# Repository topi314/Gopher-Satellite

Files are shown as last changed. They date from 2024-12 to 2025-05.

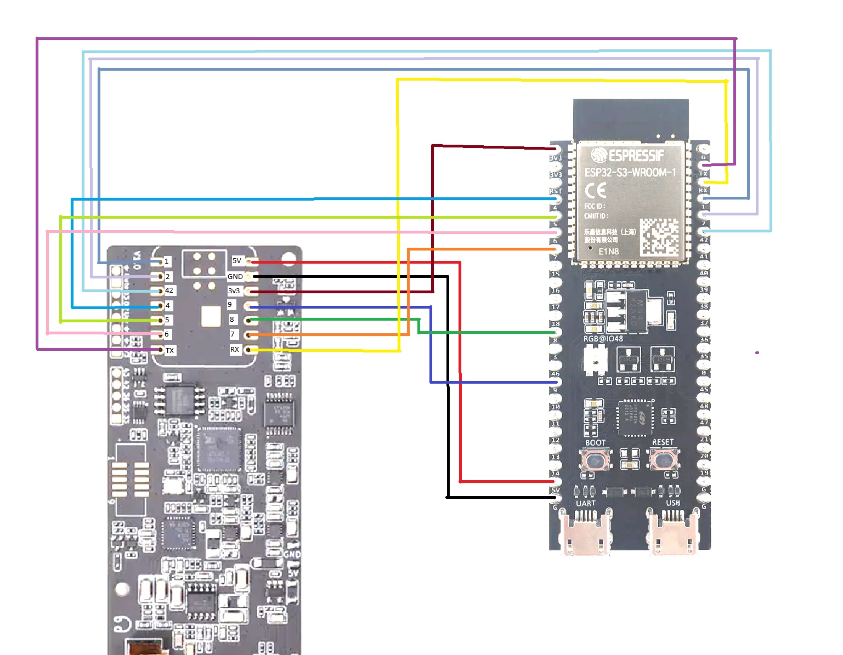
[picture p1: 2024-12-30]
instructions/images/respeaker-esp-pinout.jpg

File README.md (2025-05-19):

# Gopher Satellite

Gopher Satellite is a DIY device that works as a satellite for Home Assistant Assist.

## It is based on [Koala-Satellite](https://github.com/formatBCE/Koala-Satellite) from [formatBCE](https://github.com/formatBCE) check it out and buy him a coffee :coffee:!

#### Main characteristics:

- two far-field microphones, coupled with XMOS chip XU-316 for noise cancelation and voice recognition;
- 16bit 48kHz audio output;
- 5W speaker to use for speech responses, announcements, chimes or music;
- hardware mute button;
- rotary encoder for volume change and other adjustments;
- RGB LED for status displaying or mood lighting;
- 3.5mm line-out jack to connect external speaker.

#### Appreciation

I'd like to thank to formatBCEmm NabuCasa team and Home Assistant project - this project firmware is almost completely based on their work, and created for Home Assistant exclusively.
My dedicated appreciation goes to the [Voice PE](https://github.com/esphome/home-assistant-voice-pe) team, that made all of this possible.
Also, i'm thankful for continuous support from Seeed developers. We spent days debugging Respeaker Lite software. Now it works great!

#### How is it different from [Koala-Satellite](https://github.com/formatBCE/Koala-Satellite)?\

TLDR: I got some slightly different hardware.

//TODO: state different hardware

#### How is it different from Home Assistant [Voice PE](https://www.home-assistant.io/voice-pe)?

They're actually pretty similar. I used PE ESPHome software as the base for Koala software, and many parts are working identically.
They connect to Home Assistant in the same way and have identical possibilities.
Koala is just something you can assemble yourself from widely accessible parts.
Also it has pretty decent for size audio speaker and doesn't have external sensors connectors.

#### How is it different from [this repository](https://github.com/formatBCE/Respeaker-Lite-ESPHome-integration)?

I started to work with [Respeaker Lite](https://www.seeedstudio.com/ReSpeaker-Lite-p-5928.html) several months ago.
That repository was my attempt to put everything i know together.
All the process is pretty much documented in [this Home Assistant Community thread](https://community.home-assistant.io/t/respeaker-lite-new-seeed-studio-voice-assistant-development-kit-hardware-combine-esp32-with-xmos-xu316-dsp-chip-for-advanced-au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).
At some point i made Echo-Pop-like enclosure to the Respeaker Lite Kit. But it had disadvantages, like gluing face plate (or fabric), no access to ESP and Respeaker USB ports, lack of volume controls and rudimentary LED.
So i started thinking on real device. Here it is.

#### Why not use [Respeaker Lite with pre-soldered XIAO ESP32-S3 board](https://www.seeedstudio.com/ReSpeaker-Lite-Voice-Assistant-Kit-p-5929.html)? Isn't that easier and cheaper?

Yes, it is. But pretty much all exposed ESP GPIO pins are used by Respeaker in that configuration. So there's no way to use more elements like rotary or LED strip.
Also, current configuration hides nicely USB power cable (which is also ESP32 data cable), and allows exposing RESET/BOOT buttons for flashing.
If you're using pre-soldered version, you may check [this PR by @rananna](https://github.com/formatBCE/Koala-Satellite/pull/5) _(Thank you!)_.
Or even go full bananas and use it without dedicated LED strip (top LED should work okay) - just adjust LED diffuser color to your like.

### [Here's how you make one for yourself.](/instructions/assembly.md)

### Check main abilities [here on Respeaker repository](https://github.com/formatBCE/Respeaker-Lite-ESPHome-integration/tree/main?tab=readme-ov-file#current-abilities) - they're identical

### What if i don't want or cannot build it myself?

Create issue in this repository to let me know, that you need fully assembled device (or just printed enclosure for it). I will consider selling if demand is there. :)

"Buy Me A Coffee" (https://www.buymeacoffee.com/formatbce)

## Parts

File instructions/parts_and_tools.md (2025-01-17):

### Parts used

- microphones and DAC/AMP: Respeaker Lite board (bare board, without XIAO-S3 soldered on, like [this](https://www.seeedstudio.com/ReSpeaker-Lite-p-5928.html));
- main board: ESP32-S3 DevkitC N16R8 like [this](https://www.amazon.de/dp/B0DHJXTYBJ) (they seem to have issues with wifi & TX pin);
- rotary encoder: KY-040 ([i used this](https://a.co/d/8K1tguS));
- LED: 144 diodes/meter addressable WS2812B, 43 diodes long ([i used this](https://a.co/d/c7r4G9y));
- speaker: 2" 4Ohm 5W ([example](https://a.co/d/cEpEeNt));
- 10x M3 screws ([i used this set](https://a.co/d/e6pNfBu));
- 10x threaded inserts ([i used this](https://a.co/d/bMeMx9B));
- Jst 2.0 Ph 2-Pin Connector (male and female) for speaker like [this](https://a.co/d/aUkOTCS);
- some 3-wired male-female connector for easy LED strip connection ([i used one from this kit](https://a.co/d/9OdHJpC));
- cords of various length;
- 4x sticky rubber pads (to isolate enclosure vibrations from surface it's standing on).

### Tools used

- soldering iron and accessories;
- screwdriver or allen wrench for screws.

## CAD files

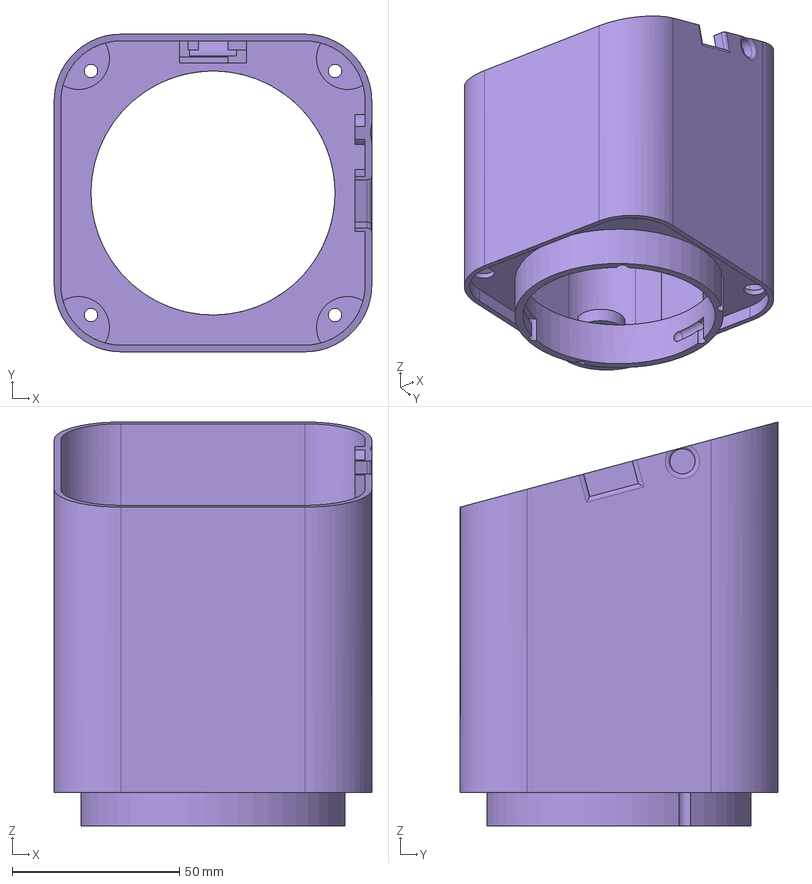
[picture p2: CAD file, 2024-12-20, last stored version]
casing/step/Main casing.step
95.0 x 95.0 x 120.8 mm

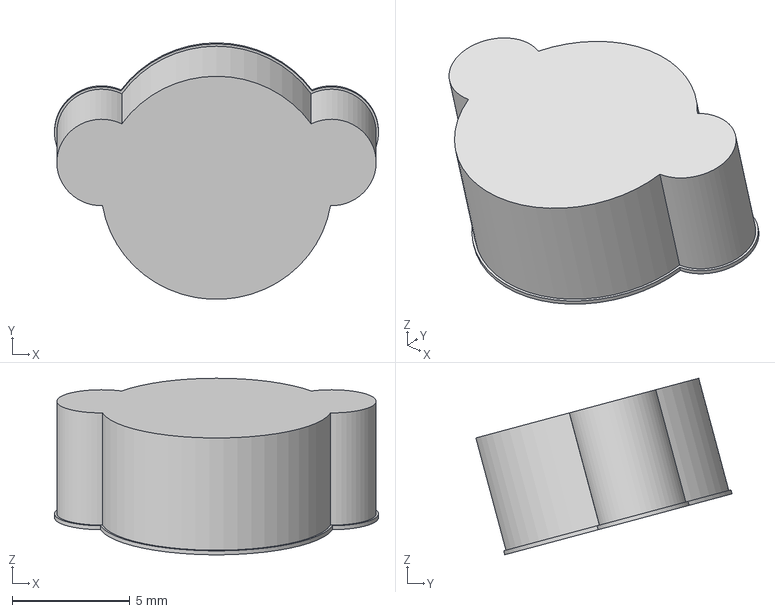
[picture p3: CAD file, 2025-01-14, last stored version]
casing/step/Top LED cover.step
13.7 x 10.9 x 7.49 mm

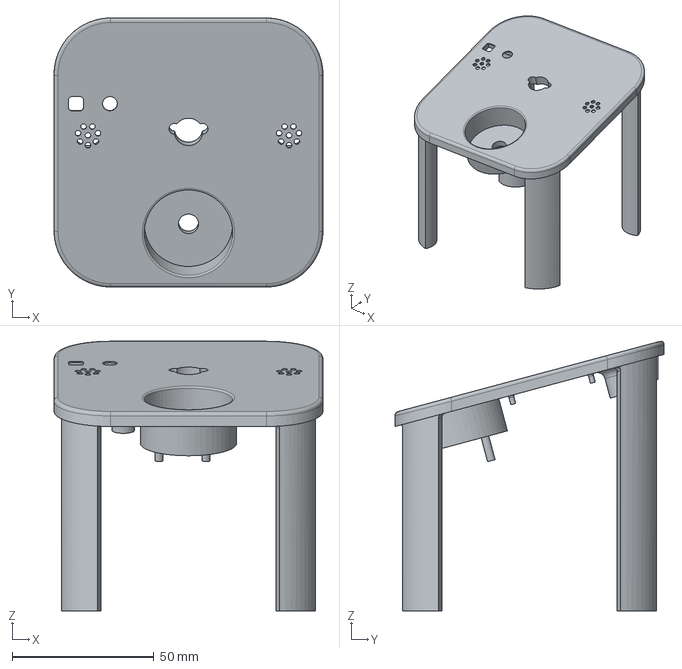
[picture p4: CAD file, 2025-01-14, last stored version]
casing/step/Face plate for top LED cover.step
95.0 x 95.0 x 95.2 mm

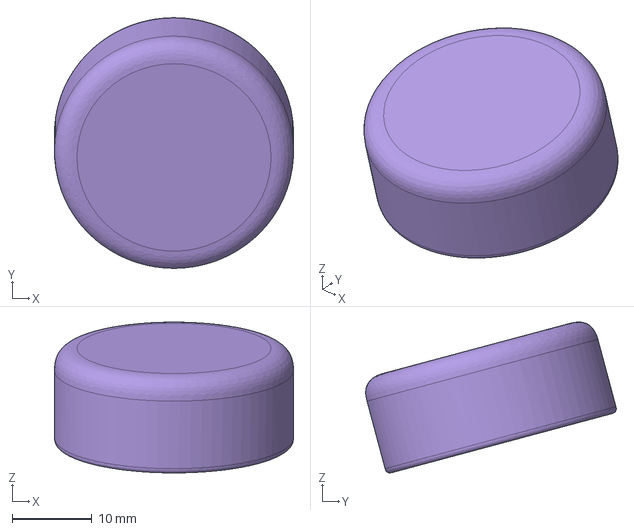
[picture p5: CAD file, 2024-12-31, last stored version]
casing/step/Knob.step
30.0 x 31.4 x 18.9 mm

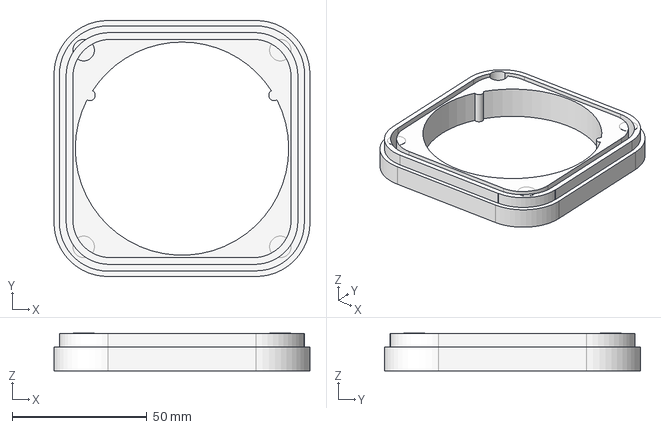
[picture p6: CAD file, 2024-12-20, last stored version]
casing/step/LED diffuser.step
95.0 x 95.0 x 14.0 mm

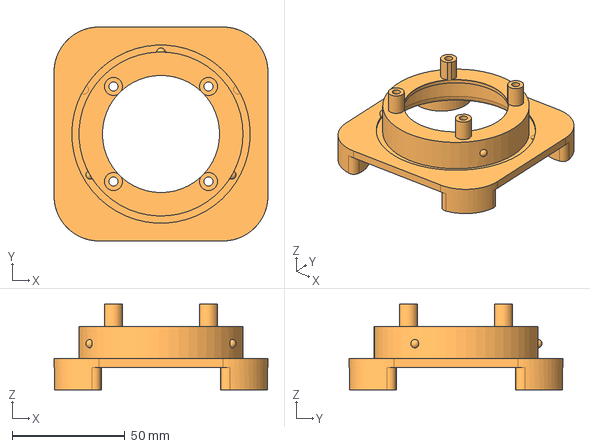
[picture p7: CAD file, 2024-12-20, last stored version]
casing/step/Speaker plate.step
95.0 x 95.0 x 38.0 mm

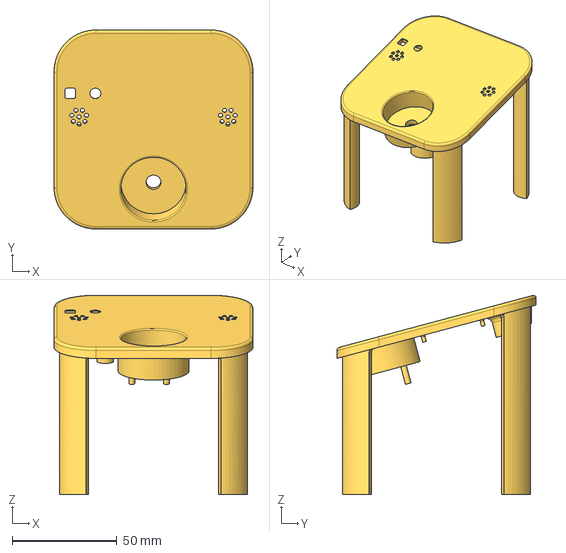
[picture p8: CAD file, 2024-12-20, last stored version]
casing/step/Face plate.step
95.0 x 95.0 x 95.2 mm

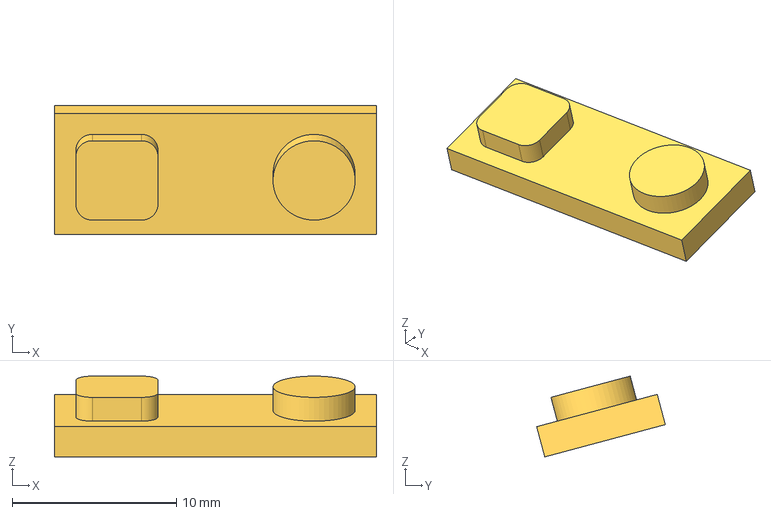
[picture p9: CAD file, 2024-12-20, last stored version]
casing/step/Buttons.step
19.6 x 7.83 x 4.92 mm

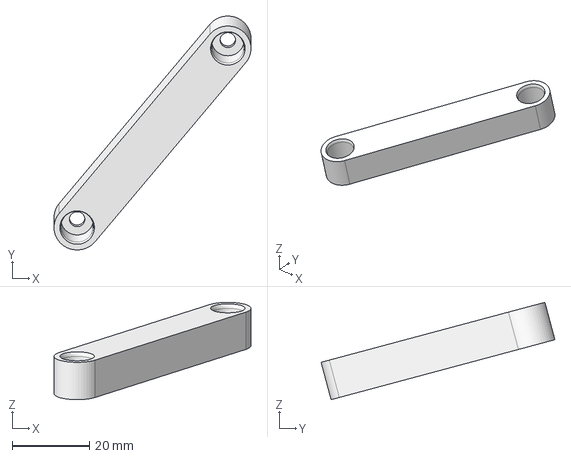
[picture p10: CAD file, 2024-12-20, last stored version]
casing/step/Bracket.step
51.0 x 60.5 x 25.2 mm

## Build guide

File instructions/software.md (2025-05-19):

## Installing the Gopher firmware

### Flashing DFU software to Respeaker Lite

To flash Respeaker board with correct software, you can use [included sowtware](/respeaker_lite_i2s_dfu_firmware_48k_v1.1.0.bin) (or take one with version >= 1.1.0 and 48kHz sample rate from [official repo](https://github.com/respeaker/ReSpeaker_Lite/tree/master/xmos_firmwares)) with [instructions from Seeed site](https://wiki.seeedstudio.com/xiao_respeaker/#flash-the-i2s-firmware).

#### _Please re-insert the board after flash and make sure that displayed version is correct one._

### DFU software auto-update
Since version 2025.2.2, the Koala firmware includes corresponding DFU firmware for Respeaker Lite board. On first start after update, new firmware will be installed to Respeaker automatically. You will see Respeaker LED flashing yellow, while installing, and green on successful install.
So now there's no need to update DFU firmware. Woohoo!

### Flashing ESPHome configuration to ESP32-S3 board

There's a configuration available: [dashboard](/config/gopher-dashboard.yaml). Also you will need to copy [base config YAML](/config/common/gopher-base.yaml) into `common` directory in your ESPHome root folder. Alternatively, you can copy everything from `gopher-base.yaml` to the chosen config and merge everything inside.

Build the firmware with ESPHome and flash it with your method of choice.

### Connecting to Home Assistant

- I'm sure you already know how to connect ESPHome devices to Home Assistant. If it's your first time, please check the [official documentation](https://www.home-assistant.io/integrations/esphome/).
- In case of Factory firmware you will need to connect the device to the WiFi first. Check [Improv docs](https://www.home-assistant.io/integrations/improv_ble/) for details.
  _**(When asked to authorize by pressing button on device, use small round button!)**_
- The voice satellite onboarding wizard will help you setup the pipeline and wake word.

### Using the alarm functionality.
Since 2025.4.1, the device has built-in alarm, that you can setup and use in your smart home. Check [this short tutorial](https://github.com/formatBCE/Respeaker-Lite-ESPHome-integration/blob/ae414e06fea8334e726837d5dbe72a55645b3445/readme/alarms.md) on how to set it up!

### _Happy tinkering!_

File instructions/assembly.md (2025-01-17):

## Gopher assembly process.

### First, check out and order required [parts and tools](parts_and_tools.md).

You don't have to use exactly the parts i used - but make sure that your parts will fit to the casing.
For example, threaded inserts holes are 4mm, count on that.
The rotary encoder is pretty specific, but it's widely accessible.
Same goes to ESP32-S3 board. Make sure it has sticking antenna - the casing made for it. You'll find over9000 clones on Amazon, and mostly (!) they will be decent. Just make sure the board works before proceeding.

### Prepare guts

- Bridge buttons on Respeaker Lite to corresponding pins (`USR` to `D2`, `Mute` to `D3`).
- Bridge `IN-OUT` and `RGB` with solder on ESP board.
- Solder the male Jst 2.0 Ph 2-Pin Connector to the speaker. Keep the cable short, ~3cm.
- Solder the female Jst 2.0 Ph 2-Pin Connector to the Respeaker Lite. You will find corresponding pads on Respeaker board near the soldered JST connector (marked + and -). Check the cables polarity. Make the cable long, so it sticks from the bottom of main casing, when Respeaker is on top (~12cm).
- Cut 43 LED long piece of WS2812 strip. Make sure it will fit LED diffuser slot nicely. Start from round hole, and move clockwise when placing the strip into diffuser.
- Solder cables of 3-wire connector male part to the LED strip. Keep these cables ~5cm long. Check the wiring. I prefer to color-code (5v -> red, GND -> black, data -> other colour).
- Solder cables of 3-wire LED connector female part to the ESP board. Make these cables ~7cm long.
  - power -> `5V`
  - ground -> `GND`
  - data -> `GPIO13`
- Solder the rotary encoder to ESP board. Make sure cables length is enough for mounting, but not too long.
  - `+` -> `5V`
  - `GND` -> `GND`
  - `SW` -> `GPIO20`
  - `CLK` -> `GPIO47`
  - `DT` -> `GPIO21`
- Solder all Respeaker Lite pins to the ESP board. This will take some time.
  - Check pinout on [this image](images/respeaker-esp-pinout.jpg).

#### At this stage, you can [install the firmware](software.md), connect the peripherals and check that everything works.

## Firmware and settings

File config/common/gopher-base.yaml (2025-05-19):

substitutions:
  # Phases of the Voice Assistant
  # The voice assistant is ready to be triggered by a wake word
  voice_assist_idle_phase_id: "1"
  # The voice assistant is waiting for a voice command (after being triggered by the wake word)
  voice_assist_waiting_for_command_phase_id: "2"
  # The voice assistant is listening for a voice command
  voice_assist_listening_for_command_phase_id: "3"
  # The voice assistant is currently processing the command
  voice_assist_thinking_phase_id: "4"
  # The voice assistant is replying to the command
  voice_assist_replying_phase_id: "5"
  # The voice assistant is not ready
  voice_assist_not_ready_phase_id: "10"
  # The voice assistant encountered an error
  voice_assist_error_phase_id: "11"

esphome:
  project:
    name: topi314.Gopher Satellite
    version: 2025.4.0
  name: gopher-satellite
  friendly_name: Gopher Satellite
  name_add_mac_suffix: true
  min_version: 2025.3.3
  platformio_options:
    board_build.flash_mode: dio
  on_boot:
    - priority: 375
      then:
        # Reset next timer and next timer name
        - sensor.template.publish:
            id: next_timer
            state: -1
        - text_sensor.template.publish:
            id: next_timer_name
            state: "-1"
        # Run the script to refresh the LED status
        - script.execute: control_leds
        # If after 10 minutes, the device is still initializing (It did not yet connect to Home Assistant), turn off the init_in_progress variable and run the script to refresh the LED status
        - delay: 10min
        - if:
            condition:
              lambda: return id(init_in_progress);
            then:
              - lambda: id(init_in_progress) = false;
              - script.execute: control_leds
  on_shutdown:
    then:
      # Prevent loud noise on software restart
      - lambda: id(respeaker).mute_speaker();

esp32:
  board: esp32-s3-devkitc-1
  variant: esp32s3
  flash_size: 16MB
  framework:
    type: esp-idf
    version: recommended
    sdkconfig_options:
      CONFIG_ESP32S3_DEFAULT_CPU_FREQ_240: "y"
      CONFIG_ESP32S3_DATA_CACHE_64KB: "y"
      CONFIG_ESP32S3_DATA_CACHE_LINE_64B: "y"
      CONFIG_ESP32S3_INSTRUCTION_CACHE_32KB: "y"

      CONFIG_BT_ALLOCATION_FROM_SPIRAM_FIRST: "y"
      CONFIG_BT_BLE_DYNAMIC_ENV_MEMORY: "y"

      CONFIG_MBEDTLS_EXTERNAL_MEM_ALLOC: "y"
      CONFIG_MBEDTLS_SSL_PROTO_TLS1_3: "y" # TLS1.3 support isn't enabled by default in IDF 5.1.5

wifi:
  id: wifi_id
  power_save_mode: none
  fast_connect: ${fast_connect}
  output_power: 19dB # seems like wifi on my board sucks lol
  on_connect:
    - script.execute: control_leds
  on_disconnect:
    - script.execute: control_leds

logger:
  level: debug
  initial_level: debug
  logs:
    sensor: WARN # avoids logging debug sensor updates
  # hardware_uart: uart0 #Uncomment to see serial logs via USB connection. Comment out after debufgging - this line introduces noise on speaker...

select:
  - platform: logger
    id: logger_select
    name: Logger Level
    disabled_by_default: true

debug:
  update_interval: 5s

api:
  id: api_id
  actions:
    - action: start_va
      then:
        - voice_assistant.start
    - action: stop_va
      then:
        - voice_assistant.stop
  on_client_connected:
    - script.execute: control_leds
  on_client_disconnected:
    - script.execute: control_leds

# Uncomment this, if you have problems with text-to-speech because of Home Assistant HTTPS internal URL
# http_request:
#   verify_ssl: false

ota:
  - platform: esphome
    id: ota_esphome

i2c:
  - id: internal_i2c
    sda: GPIO5
    scl: GPIO6
    frequency: 400kHz
  - id: display_i2c
    sda: GPIO11
    scl: GPIO10
    frequency: 400kHz

psram:
  mode: octal
  speed: 80MHz

globals:
  # Global initialization variable. Initialized to true and set to false once everything is connected. Only used to have a smooth "plugging" experience
  - id: init_in_progress
    type: bool
    restore_value: false
    initial_value: "true"
  # Global variable tracking the phase of the voice assistant (defined above). Initialized to not_ready
  - id: voice_assistant_phase
    type: int
    restore_value: false
    initial_value: ${voice_assist_not_ready_phase_id}
  # Global variable storing the time zone
  - id: saved_time_zone
    type: std::string
    restore_value: true
    initial_value: '"UTC0"'
  # Global variable storing the first active timer
  - id: first_active_timer
    type: voice_assistant::Timer
    restore_value: false
  # Global variable storing if a timer is active
  - id: is_timer_active
    type: bool
    restore_value: false
  # Global variable storing the current ringing timer
  - id: current_ringing_timer
    type: voice_assistant::Timer
    restore_value: false

# Time sync from Home Assistant
time:
  - platform: homeassistant
    id: homeassistant_time
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

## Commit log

2024-12-20 Added casing 3d files
    [Bracket.step, Buttons.step, Face plate.step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]
2024-12-31 Updated Knob - hole a bit bigger.
    [Knob.step]
2025-01-13 Added some HTTPS fixes. Added switches for sounds control. Added next timer sensors.
    [koala-base.yaml]
2025-01-13 Update README.md - include PR for pre-soldered Respeaker.
2025-01-14 Updated instructions for top LED cover variant.
2025-01-17 adjust files for gopher satellite
    [Bracket.step, Buttons.step, Face plate.step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]
2025-01-18 Add stl and 3mf file format for 3d prints
    [Bracket.3mf, Bracket.stl, Buttons.3mf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]
2025-01-18 Add info about STL and 3MF to instructions.
2025-02-06 Add info about mandatory buttons bridging
2025-02-09 assembly.md - typo fix
2025-02-19 Update to 2025.2.0
    - player updated
    - timers updated
    - added (disabled by default) logging level selection
    - changed animations a bit
2025-03-13 2025.3.0 (#12)
    - more granular volume control;
    - fix for corrupted media player name;
    - lowered VAD probability cut-off to reduce false-negatives.
    [koala-base.yaml]
2025-04-01 Release 2025.4.0 (#15)
    improvements to media player;
    ESPHome 2025.3.3;
    cloud error sound (from Voice PE).
    [koala-base.yaml]
2025-04-10 2025.4.1 - alarms, TTS URI sensor replacement with event. (#17)
    - changes for VPE: Stop action cancels any continue conversation;
    - removed TTS URI sensor, replaced with event esphome.tts_uri;
    - added daily alarm functionality.
    [koala-base.yaml]
2025-04-13 2025.4.2 (#18)
    - better stop word handling
    - fix for alarm crash
    - added STT event
    [koala-base.yaml]
2025-05-19 remove alarm stuff
    [Face plate for top LED cover.step, Top LED cover.step]
2025-05-19 uart is bad
